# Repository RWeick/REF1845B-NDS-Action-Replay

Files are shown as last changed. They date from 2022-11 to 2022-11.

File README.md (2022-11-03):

# REF1845B-NDS-Action-Replay
The full schematic, flash dump, and gerbers for the Nintendo DS Action Replay by Datel. The apparent micro SD card slot footprint on the back of the PCB is not connected properly. It is possibly a JTAG connection.

PCB Thickness: 0.8 mm

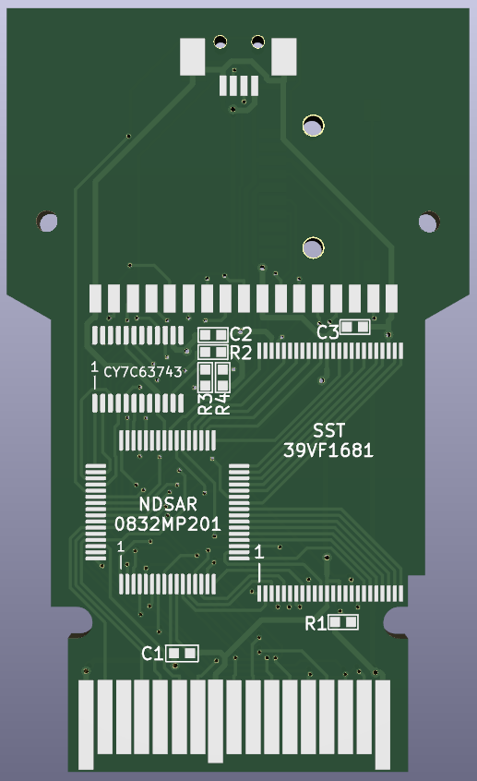
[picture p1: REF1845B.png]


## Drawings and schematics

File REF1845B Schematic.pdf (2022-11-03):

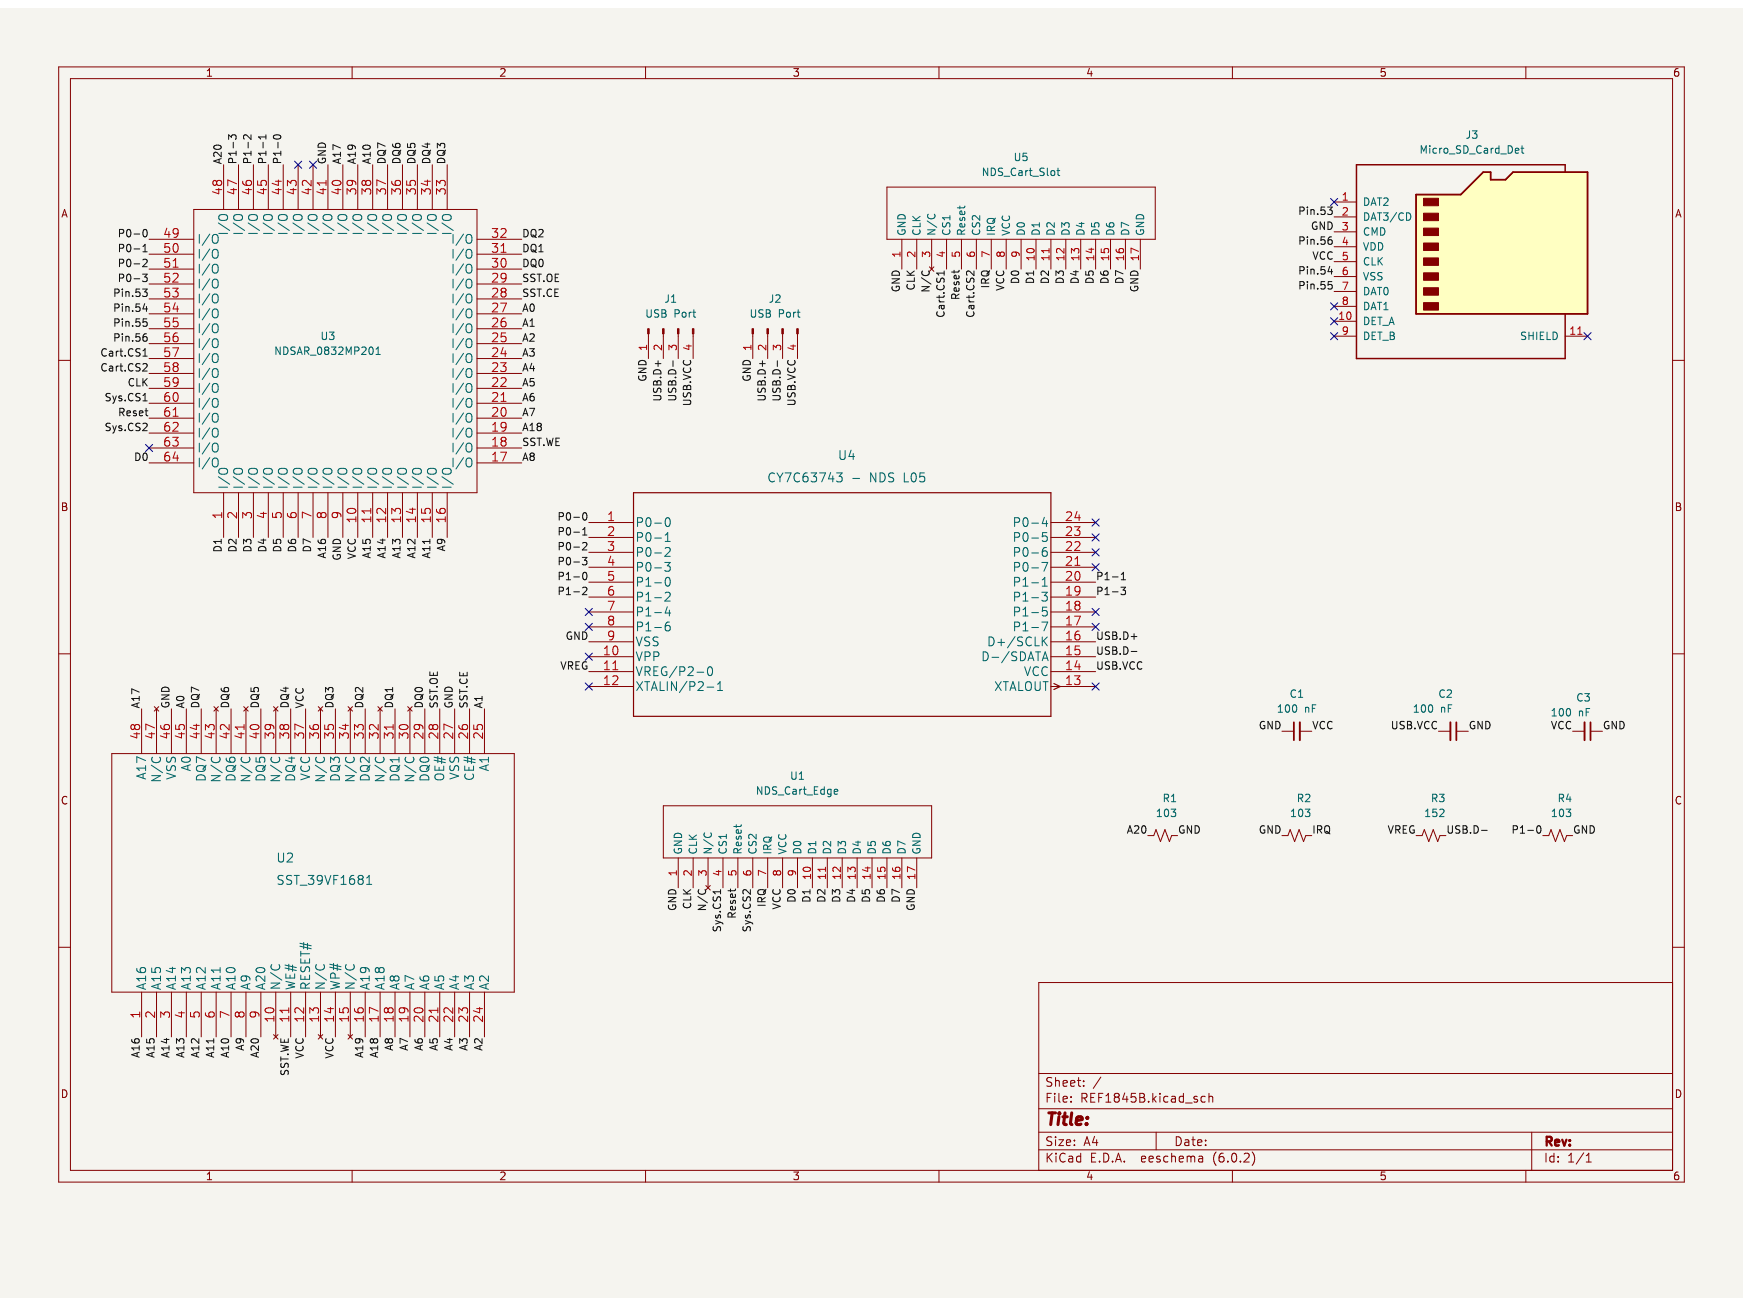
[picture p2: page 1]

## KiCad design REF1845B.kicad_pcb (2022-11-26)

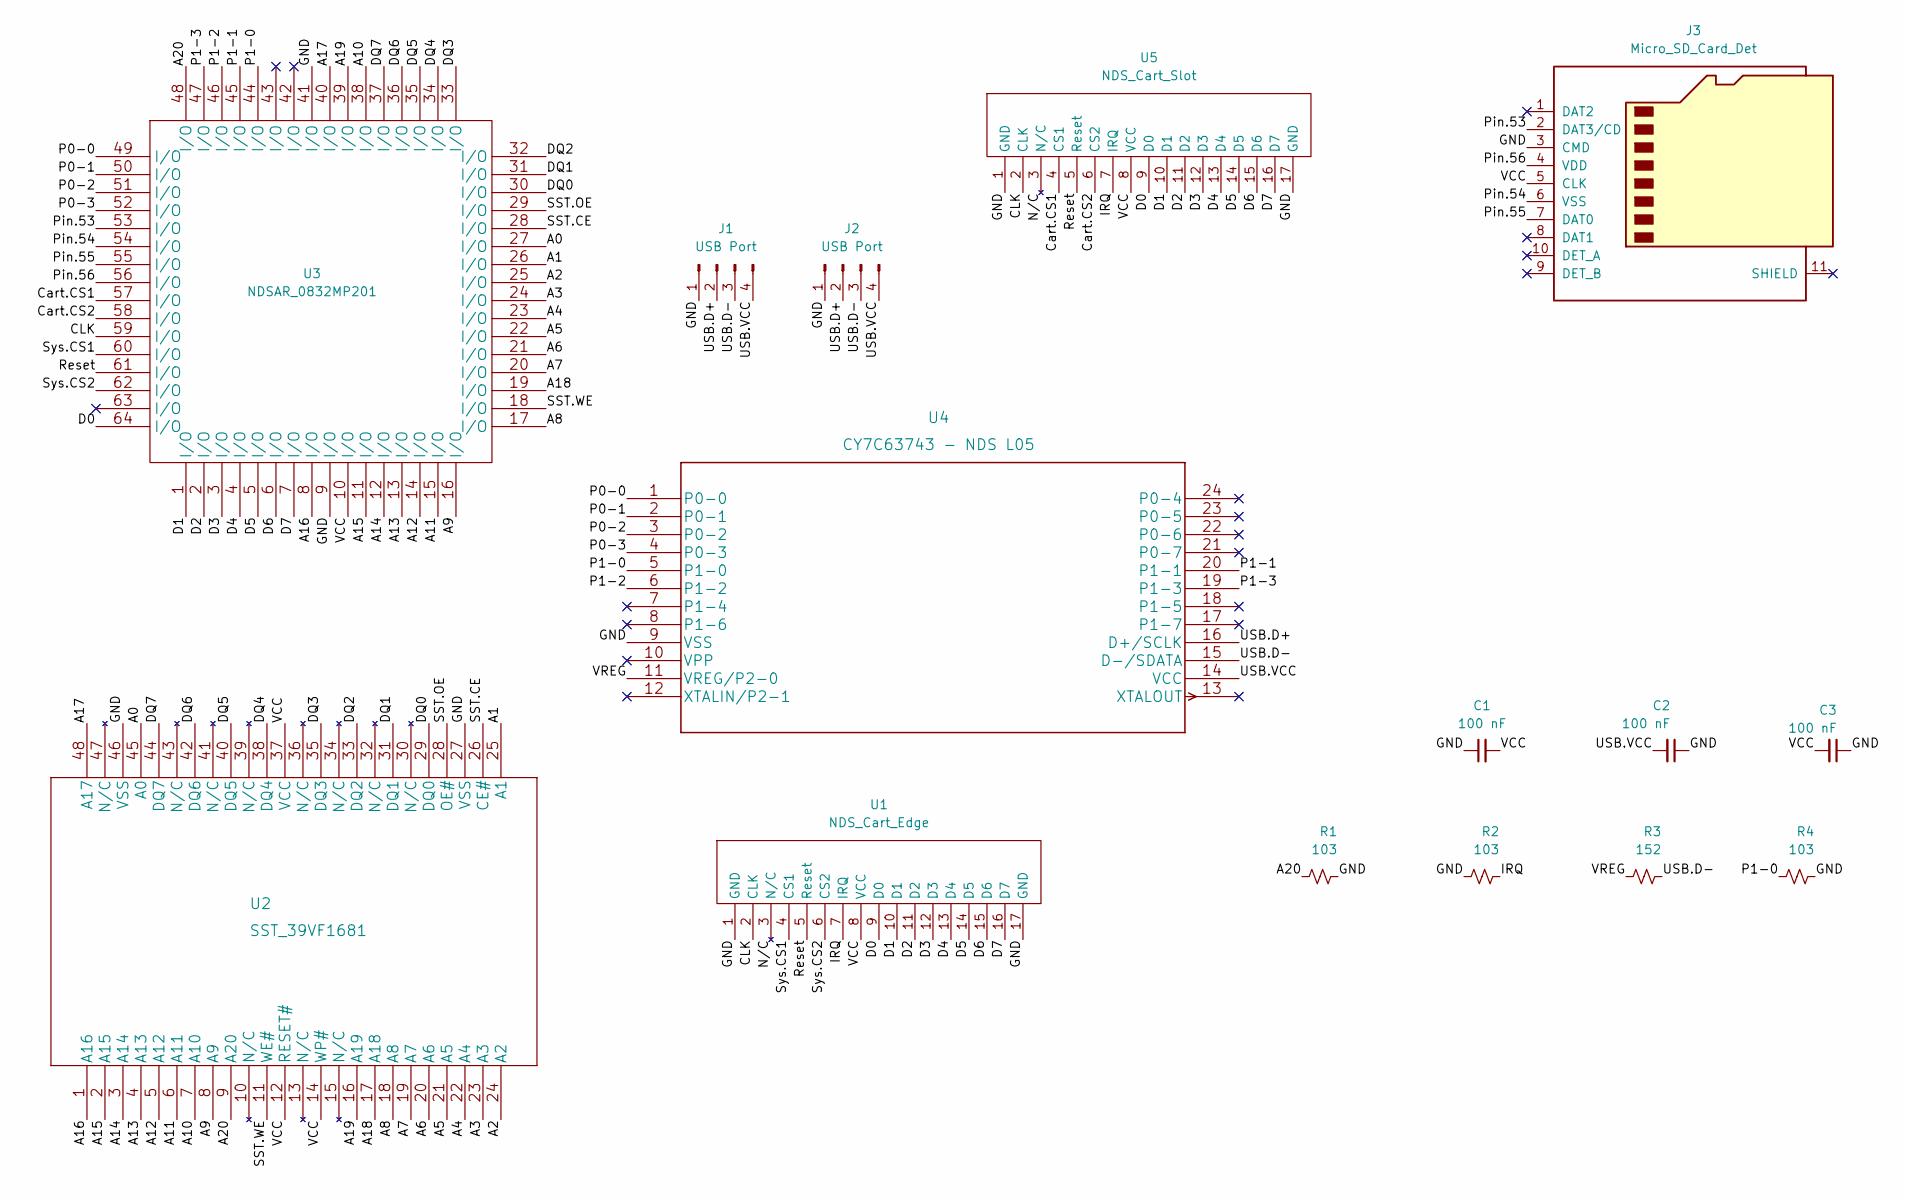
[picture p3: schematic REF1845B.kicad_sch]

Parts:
C1, C2, C3: 100 nF; Little SMD
J1, J2: USB Port; USB Adapter
J3: Micro_SD_Card_Det; Micro SD Card
R1, R2, R4: 103; Little SMD
R3: 152; Little SMD
U1: NDS_Cart_Edge; Edge Connector
U2: SST_39VF1681; SOP50P2000X120-48N
U3: NDSAR_0832MP201; 64 pin FPGA DS AR
U4: CY7C63743 - NDS L05; CY7C63743 24 lead quarter size
U5: NDS_Cart_Slot; DS Slot

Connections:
/A0: U2.45 (A0), U3.27 (I/O)
/A1: U2.25 (A1), U3.26 (I/O)
/A2: U2.24 (A2), U3.25 (I/O)
/A3: U2.23 (A3), U3.24 (I/O)
/A4: U2.22 (A4), U3.23 (I/O)
/A5: U2.21 (A5), U3.22 (I/O)
/A6: U2.20 (A6), U3.21 (I/O)
/A7: U2.19 (A7), U3.20 (I/O)
/A8: U2.18 (A8), U3.17 (I/O)
/A9: U2.8 (A9), U3.16 (I/O)
/A10: U2.7 (A10), U3.38 (I/O)
/A11: U2.6 (A11), U3.15 (I/O)
/A12: U2.5 (A12), U3.14 (I/O)
/A13: U2.4 (A13), U3.13 (I/O)
/A14: U2.3 (A14), U3.12 (I/O)
/A15: U2.2 (A15), U3.11 (I/O)
/A16: U2.1 (A16), U3.8 (I/O)
/A17: U2.48 (A17), U3.40 (I/O)
/A18: U2.17 (A18), U3.19 (I/O)
/A19: U2.16 (A19), U3.39 (I/O)
/A20: R1.2, U2.9 (A20), U3.48 (I/O)
/CLK: U1.2 (CLK), U3.59 (I/O), U5.2 (CLK)
/Cart.CS1: U3.57 (I/O), U5.4 (CS1)
/Cart.CS2: U3.58 (I/O), U5.6 (CS2)
/D0: U1.9 (D0), U3.64 (I/O), U5.9 (D0)
/D1: U1.10 (D1), U3.1 (I/O), U5.10 (D1)
/D2: U1.11 (D2), U3.2 (I/O), U5.11 (D2)
/D3: U1.12 (D3), U3.3 (I/O), U5.12 (D3)
/D4: U1.13 (D4), U3.4 (I/O), U5.13 (D4)
/D5: U1.14 (D5), U3.5 (I/O), U5.14 (D5)
/D6: U1.15 (D6), U3.6 (I/O), U5.15 (D6)
/D7: U1.16 (D7), U3.7 (I/O), U5.16 (D7)
/DQ0: U2.29 (DQ0), U3.30 (I/O)
/DQ1: U2.31 (DQ1), U3.31 (I/O)
/DQ2: U2.33 (DQ2), U3.32 (I/O)
/DQ3: U2.35 (DQ3), U3.33 (I/O)
/DQ4: U2.38 (DQ4), U3.34 (I/O)
/DQ5: U2.40 (DQ5), U3.35 (I/O)
/DQ6: U2.42 (DQ6), U3.36 (I/O)
/DQ7: U2.44 (DQ7), U3.37 (I/O)
/GND: C1.1, C2.2, C3.2, J1.1, J2.1, J3.3 (CMD), R1.1, R2.2, R4.1, U1.1 (GND), U1.17 (GND), U2.27 (VSS), U2.46 (VSS), U3.9 (I/O), U3.41 (I/O), U4.9 (VSS), U5.1 (GND), U5.17 (GND)
/IRQ: R2.1, U1.7 (IRQ), U5.7 (IRQ)
/P0-0: U3.49 (I/O), U4.1 (P0-0)
/P0-1: U3.50 (I/O), U4.2 (P0-1)
/P0-2: U3.51 (I/O), U4.3 (P0-2)
/P0-3: U3.52 (I/O), U4.4 (P0-3)
/P1-0: R4.2, U3.44 (I/O), U4.5 (P1-0)
/P1-1: U3.45 (I/O), U4.20 (P1-1)
/P1-2: U3.46 (I/O), U4.6 (P1-2)
/P1-3: U3.47 (I/O), U4.19 (P1-3)
/Pin.53: J3.2 (DAT3/CD), U3.53 (I/O)
/Pin.54: J3.6 (VSS), U3.54 (I/O)
/Pin.55: J3.7 (DAT0), U3.55 (I/O)
/Pin.56: J3.4 (VDD), U3.56 (I/O)
/Reset: U1.5 (Reset), U3.61 (I/O), U5.5 (Reset)
/SST.CE: U2.26 (CE#), U3.28 (I/O)
/SST.OE: U2.28 (OE#), U3.29 (I/O)
/SST.WE: U2.11 (WE#), U3.18 (I/O)
/Sys.CS1: U1.4 (CS1), U3.60 (I/O)
/Sys.CS2: U1.6 (CS2), U3.62 (I/O)
/USB.D+: J1.2, J2.2, U4.16 (D+/SCLK)
/USB.D-: J1.3, J2.3, R3.1, U4.15 (D-/SDATA)
/USB.VCC: C2.1, J1.4, J2.4, U4.14 (VCC)
/VCC: C1.2, C3.1, J3.5 (CLK), U1.8 (VCC), U2.12 (RESET#), U2.14 (WP#), U2.37 (VCC), U3.10 (I/O), U5.8 (VCC)
/VREG: R3.2, U4.11 (VREG/P2-0)

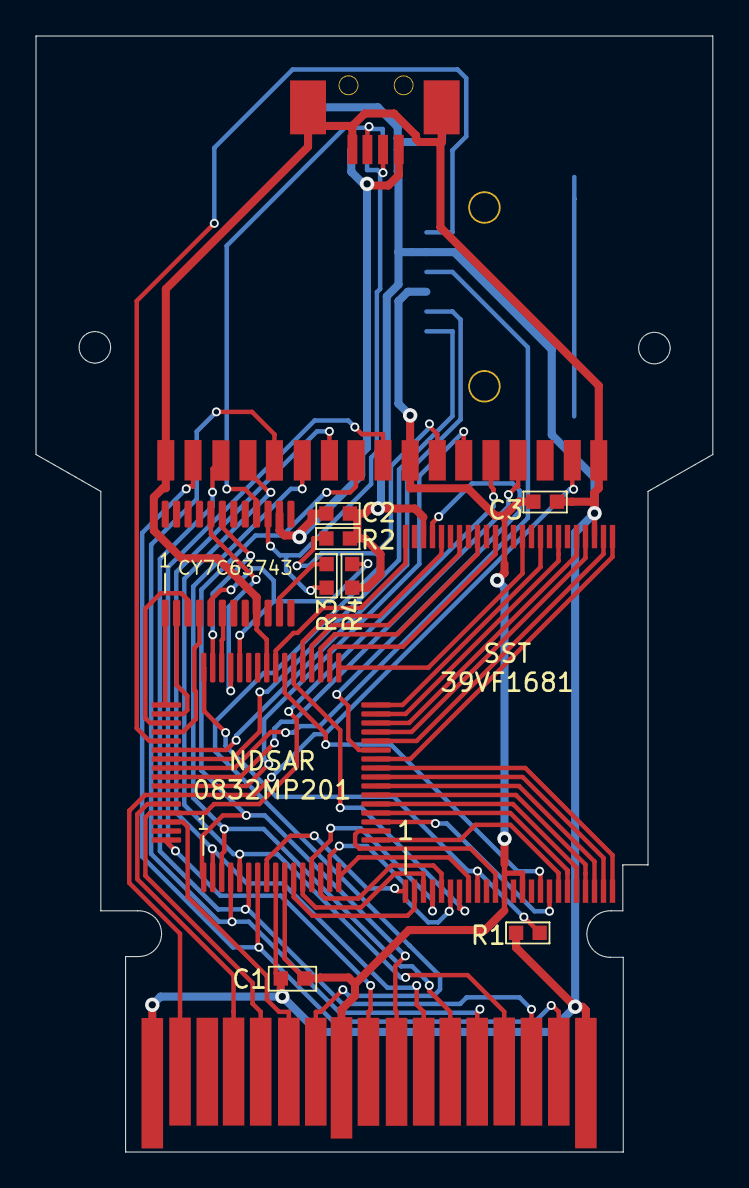
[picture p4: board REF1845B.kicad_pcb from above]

Board: 2 copper layers, 37.6 x 62.0 mm, 17 parts (1 on the bottom side), 65 nets.

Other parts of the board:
H1, H2: MountingHole_2.1mm
